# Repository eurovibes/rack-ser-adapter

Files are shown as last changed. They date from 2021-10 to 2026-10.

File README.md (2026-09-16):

<!-- SPDX-FileCopyrightText: 2021 Benedikt Spranger <b.spranger@linutronix.de> -->
<!-- SPDX-License-Identifier: CERN-OHL-S-2.0 -->






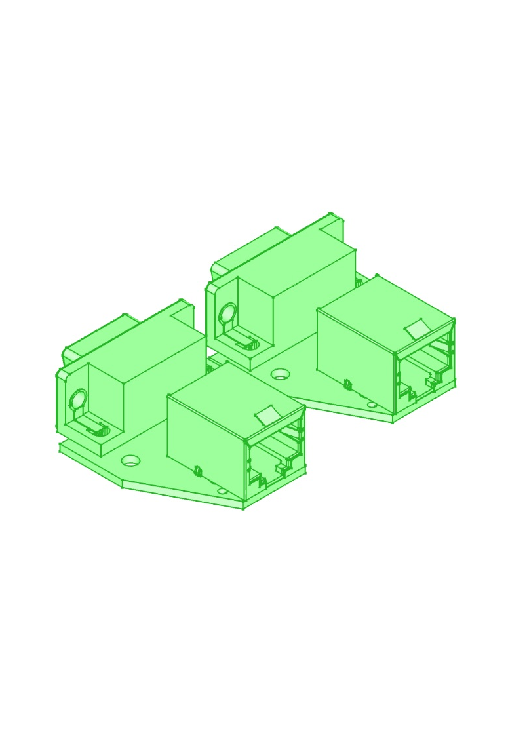
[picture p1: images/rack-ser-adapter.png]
rack-ser-adapter logo


# rack-ser-adapter -  RS232 DE-9 to EIA-561 RJ45 adapter

## Adapter pinout (EIA-561)

### 1:1

| DB-9 Pin | Signal	| RJ45 |
|---:|---|-----:|
1 | DCD | 2
2 | RxD | 5
3 | TxD | 6
4 | DTR | 3
5 | GND | 4
6 | DSR | 1
7 | RTS | 8
8 | CTS | 7
9 |  -  | -

### CROSSOVER / NULLMODEM

| RJ45 | Signal	| DB-9 Pin |
|-----:|---|---:|
1 | DTR | 4
2 | DCD | -
3 | DST | 6
4 | GND | 5
5 | TxD | 3
6 | RxD | 2
7 | RTS | 7
8 | CTS | 8
9 |  -  | -

## License rules

rack-ser-adapter is provided under the terms of the CERN-OHL-S license
version 2 as provided in the LICENSES/CERN-OHL-S-2.0 file.

Instead of adding license boilerplates to the individual files,
rack-ser-adapter uses SPDX license identifiers, which are machine parseable
and considered legaly equivalent.

The SPDX license identifier in rack-ser-adapter shall be added at the first
possible line in a file which can contain a comment. This is normally the
first line except for scripts. Scripts require the #!PATH_TO_INTERPRETER tag
in the first line; place the SPDX identifier into the second line.

The SPDX license identifier is added in form of a comment.

## Copyright and License

> Copyright Benedikt Spranger 2021.
> This source describes Open Hardware and is licensed under the CERNOHL-S v2.
> You may redistribute and modify this source and make products using it
> under the terms of the CERN-OHL-S v2 (https://ohwr.org/cern ohl s v2.txt ).
> This source is distributed WITHOUT ANY EXPRESS OR IMPLIED WARRANTY, INCLUDING
> OF MERCHANTABILITY, SATISFACTORY QUALITY AND FITNESS FOR A PARTICULAR PURPOSE.
> Please see the CERN-OHL-S v2 for applicable conditions.
> Source location: https://github.com/eurovibes/rack-ser-adapter
> As per CERN-OHL-S v2 section 4, should You produce hardware based
> on this source, You must where practicable maintain the Source Location
> visible on the external case of the rack-ser-adapter or other products you
> make using this source.

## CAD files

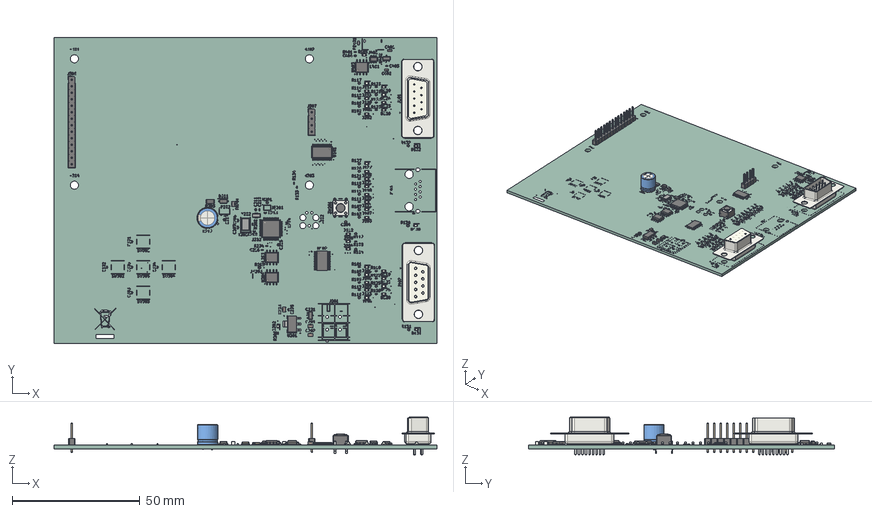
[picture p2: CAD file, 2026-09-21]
enclosure/tester.step
150.0 x 120.0 x 14.7 mm
C_0402_1005Metric x 19
R_0402_1005Metric x 40
LED_0603_1608Metric x 34
SOT-23-3
CP_Radial_D8.0mm_P3.50mm
PinHeader_1x04_P2.54mm_Vertical
PinHeader_1x14_P2.54mm_Vertical
C_0805_2012Metric x 3
SOT-23
Crystal_SMD_3215-2Pin_3.2x1.5mm
C_0603_1608Metric x 2
TSSOP-24_4.4x7.8mm_P0.65mm x 2
SW_PUSH_6mm
R_1206_3216Metric
JEITA_SOIC-8_3.9x4.9mm_P1.27mm
SOIC-8_3.9x4.9mm_P1.27mm x 2
SOT-23-6
DSUB-9_Socket_Vertical_P2.77x2.84mm_MountingHoles
SOT-223
L_0603_1608Metric
LQFP-48_7x7mm_P0.5mm
Crystal_SMD_5032-2Pin_5.0x3.2mm
DSUB-9_Pins_Vertical_P2.77x2.84mm_MountingHoles
D_SOD-123
L_0805_2012Metric
tester_silkscreen
tester_PCB

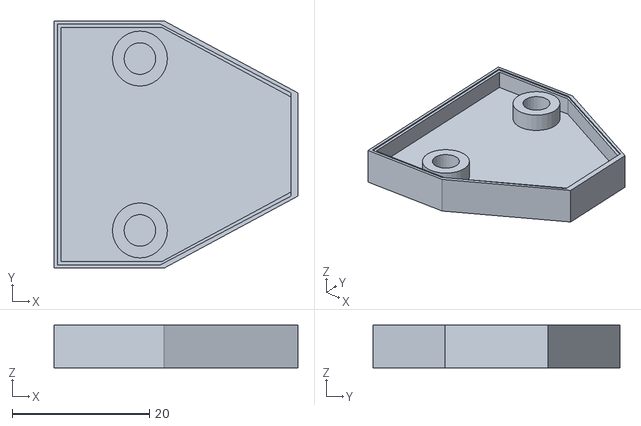
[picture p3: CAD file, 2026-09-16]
enclosure/rack-ser-adapter-rack-ser-adapter.stl
35.5 x 36.0 x 6.20

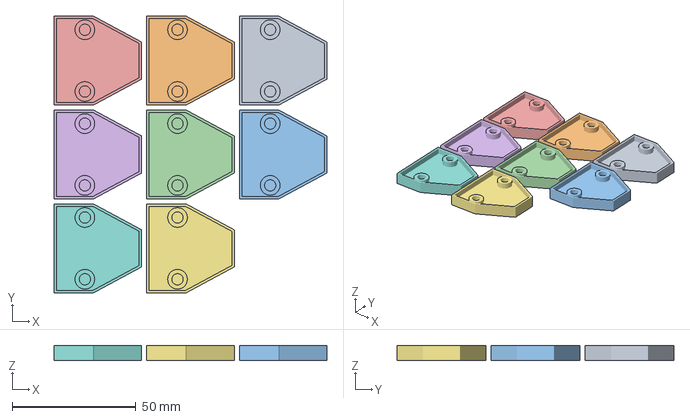
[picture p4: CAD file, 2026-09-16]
enclosure/AI3MSPRO_rack-ser-adapter-rack-ser-adapter.3mf
110.5 x 112.0 x 6.20 mm
rack-ser-adapter-rack-ser-adapter.stl x 8

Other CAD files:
enclosure/rack-ser-adapter.FCStd
enclosure/tester.FCStd

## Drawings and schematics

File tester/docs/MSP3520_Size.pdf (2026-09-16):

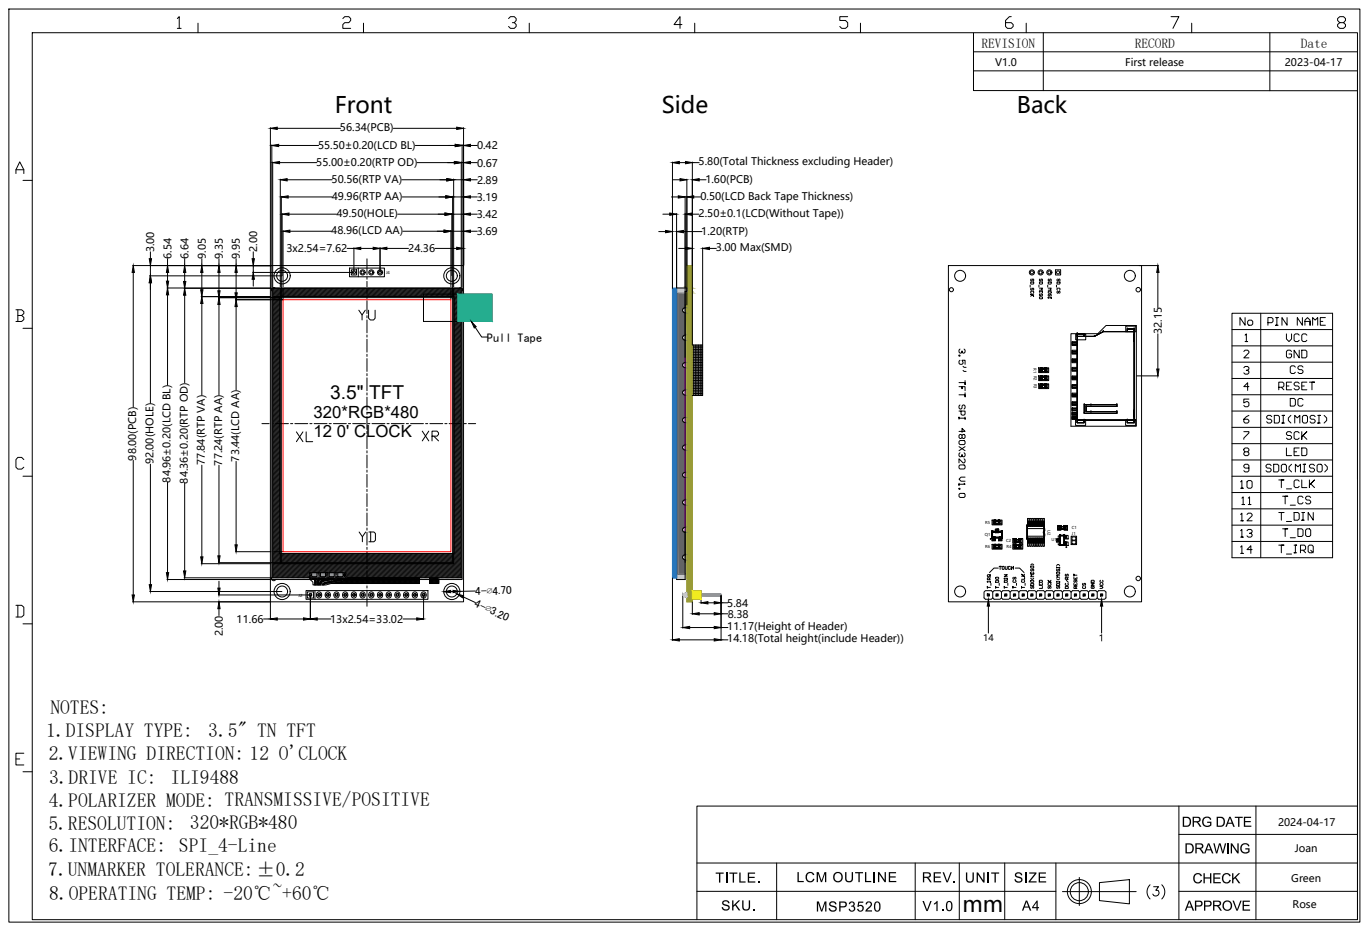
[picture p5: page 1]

3.003.69 3.42 1.60(PCB) 0.50(LCD Back Tape Thickness) 2.50±0.1(LCD(Without Tape)) 1.20(RTP) 5.80(Total Thickness excluding Header) 11.17(Height of Header) 5.84 8.38 14.18(Total height(include Header)) 3.00 Max(SMD) V1.0 First release 2023-04-17 3.5" TN TFT 12 O'CLOCK TRANSMISSIVE/POSITIVE 320*RGB*480 SPI_4-Line±0.2 -20℃~+60℃ ILI9488 V1.0 2024-04-17

73.44(LCD AA) 55.50±0.20(LCD BL) 55.00±0.20(RTP OD)

9.95 Pull Tape 3.5" TFT 320*RGB*480 12 0' CLOCK U1 R4

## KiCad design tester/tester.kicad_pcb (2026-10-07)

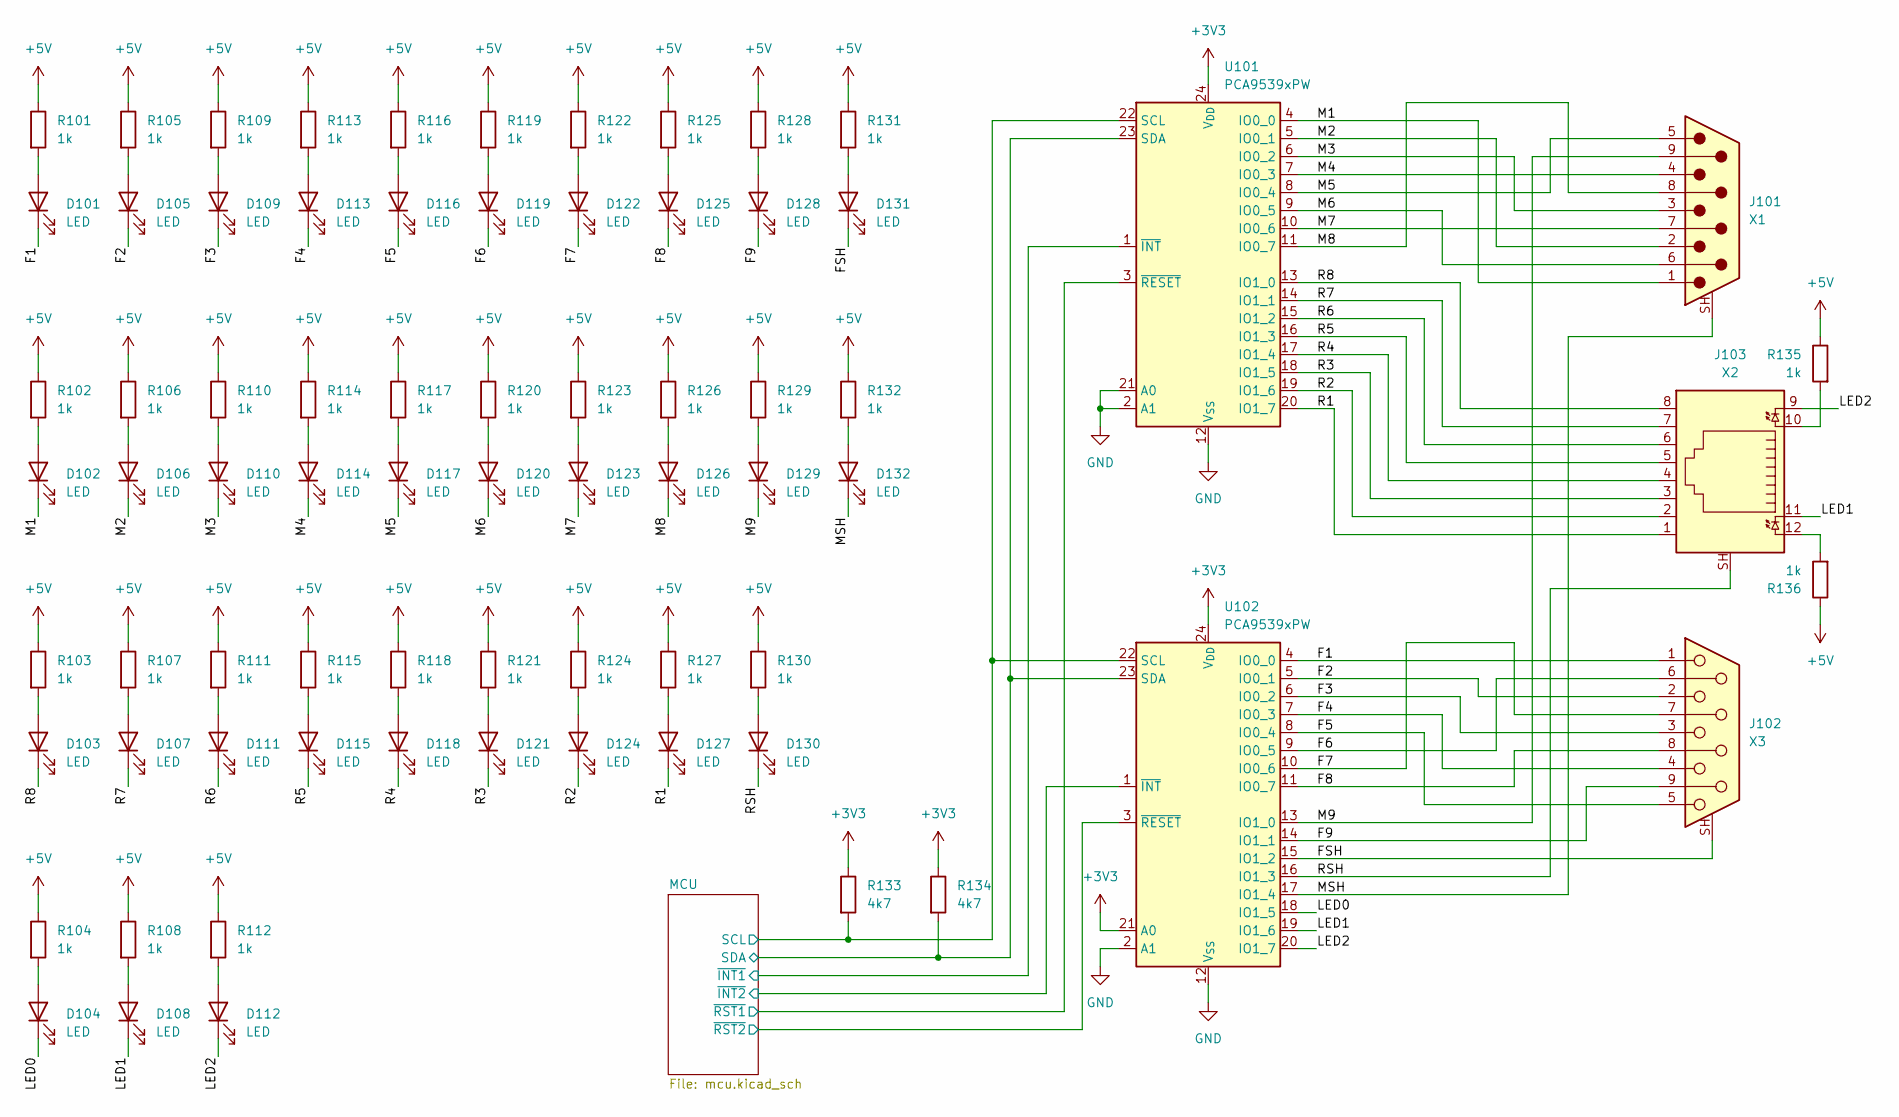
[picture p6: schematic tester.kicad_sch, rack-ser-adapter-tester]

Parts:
D101, D102, D103, D104, D105, D106, D107, D108, D109, D110, D111, D112, D113, D114, D115, D116, D117, D118, D119, D120, D121, D122, D123, D124, D125, D126, D127, D128, D129, D130, D131, D132: LED; LED_0603_1608Metric; mpn KT-0603W; LCSC# C2290
J101: X1; DSUB-9_Pins_Vertical_P2.77x2.84mm_MountingHoles; mpn DS1037-09MNAKT74-0CC
J102: X3; DSUB-9_Socket_Vertical_P2.77x2.84mm_MountingHoles; mpn DS1037-09FNAKT74-0CC
J103: X2; RJ45_Amphenol_RJHSE538X; mpn RJHSE5380
R101, R102, R103, R104, R105, R106, R107, R108, R109, R110, R111, R112, R113, R114, R115, R116, R117, R118, R119, R120, R121, R122, R123, R124, R125, R126, R127, R128, R129, R130, R131, R132, R135, R136: 1k; R_0402_1005Metric; mpn 0402WGF1001TCE; LCSC# C11702
R133, R134: 4k7; R_0402_1005Metric; mpn 0402WGF4701TCE; LCSC# C25900
U101, U102: PCA9539xPW; TSSOP-24_4.4x7.8mm_P0.65mm; mpn PCA9539PW; LCSC# C129516

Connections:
+3V3: R133.1, R134.1, U101.24 (V_{DD}), U102.21 (A0), U102.24 (V_{DD}); also elsewhere on the board
+5V: R101.1, R102.1, R103.1, R104.1, R105.1, R106.1, R107.1, R108.1, R109.1, R110.1, R111.1, R112.1, R113.1, R114.1, R115.1, R116.1, R117.1, R118.1, R119.1, R120.1, R121.1, R122.1, R123.1, R124.1, R125.1, R126.1, R127.1, R128.1, R129.1, R130.1, R131.1, R132.1, R135.1, R136.1; also elsewhere on the board
/F1: D101.1 (K), J102.1, U102.4 (IO0_0)
/F2: D105.1 (K), J102.2, U102.5 (IO0_1)
/F3: D109.1 (K), J102.3, U102.6 (IO0_2)
/F4: D113.1 (K), J102.4, U102.7 (IO0_3)
/F5: D116.1 (K), J102.5, U102.8 (IO0_4)
/F6: D119.1 (K), J102.6, U102.9 (IO0_5)
/F7: D122.1 (K), J102.7, U102.10 (IO0_6)
/F8: D125.1 (K), J102.8, U102.11 (IO0_7)
/F9: D128.1 (K), J102.9, U102.14 (IO1_1)
/FSH: D131.1 (K), J102.SH (PAD), U102.15 (IO1_2)
/LED0: D104.1 (K), U102.18 (IO1_5)
/LED1: D108.1 (K), J103.11, U102.19 (IO1_6)
/LED2: D112.1 (K), J103.9, U102.20 (IO1_7)
/M1: D102.1 (K), J101.1, U101.4 (IO0_0)
/M2: D106.1 (K), J101.2, U101.5 (IO0_1)
/M3: D110.1 (K), J101.3, U101.6 (IO0_2)
/M4: D114.1 (K), J101.4, U101.7 (IO0_3)
/M5: D117.1 (K), J101.5, U101.8 (IO0_4)
/M6: D120.1 (K), J101.6, U101.9 (IO0_5)
/M7: D123.1 (K), J101.7, U101.10 (IO0_6)
/M8: D126.1 (K), J101.8, U101.11 (IO0_7)
/M9: D129.1 (K), J101.9, U102.13 (IO1_0)
/MCU/SCL: R133.2, U101.22 (SCL), U102.22 (SCL); also elsewhere on the board
/MCU/SDA: R134.2, U101.23 (SDA), U102.23 (SDA); also elsewhere on the board
/MCU/~INT1: U101.1 (~INT); also elsewhere on the board
/MCU/~INT2: U102.1 (~INT); also elsewhere on the board
/MCU/~RST1: U101.3 (~RESET); also elsewhere on the board
/MCU/~RST2: U102.3 (~RESET); also elsewhere on the board
/MSH: D132.1 (K), J101.SH (PAD), U102.17 (IO1_4)
/R1: D127.1 (K), J103.1, U101.20 (IO1_7)
/R2: D124.1 (K), J103.2, U101.19 (IO1_6)
/R3: D121.1 (K), J103.3, U101.18 (IO1_5)
/R4: D118.1 (K), J103.4, U101.17 (IO1_4)
/R5: D115.1 (K), J103.5, U101.16 (IO1_3)
/R6: D111.1 (K), J103.6, U101.15 (IO1_2)
/R7: D107.1 (K), J103.7, U101.14 (IO1_1)
/R8: D103.1 (K), J103.8, U101.13 (IO1_0)
/RSH: D130.1 (K), J103.SH, U102.16 (IO1_3)
GND: U101.2 (A1), U101.12 (V_{SS}), U101.21 (A0), U102.2 (A1), U102.12 (V_{SS}); also elsewhere on the board
unnamed: D101.2 (A), R101.2
unnamed: D102.2 (A), R102.2
unnamed: D103.2 (A), R103.2
unnamed: D104.2 (A), R104.2
unnamed: D105.2 (A), R105.2
unnamed: D106.2 (A), R106.2
unnamed: D107.2 (A), R107.2
unnamed: D108.2 (A), R108.2
unnamed: D109.2 (A), R109.2
unnamed: D110.2 (A), R110.2
unnamed: D111.2 (A), R111.2
unnamed: D112.2 (A), R112.2
unnamed: D113.2 (A), R113.2
unnamed: D114.2 (A), R114.2
unnamed: D115.2 (A), R115.2
unnamed: D116.2 (A), R116.2
unnamed: D117.2 (A), R117.2
unnamed: D118.2 (A), R118.2
unnamed: D119.2 (A), R119.2
unnamed: D120.2 (A), R120.2
unnamed: D121.2 (A), R121.2
unnamed: D122.2 (A), R122.2
unnamed: D123.2 (A), R123.2
unnamed: D124.2 (A), R124.2
unnamed: D125.2 (A), R125.2
unnamed: D126.2 (A), R126.2
unnamed: D127.2 (A), R127.2
unnamed: D128.2 (A), R128.2
unnamed: D129.2 (A), R129.2
unnamed: D130.2 (A), R130.2
unnamed: D131.2 (A), R131.2
unnamed: D132.2 (A), R132.2
unnamed: J103.10, R135.2
unnamed: J103.12, R136.2

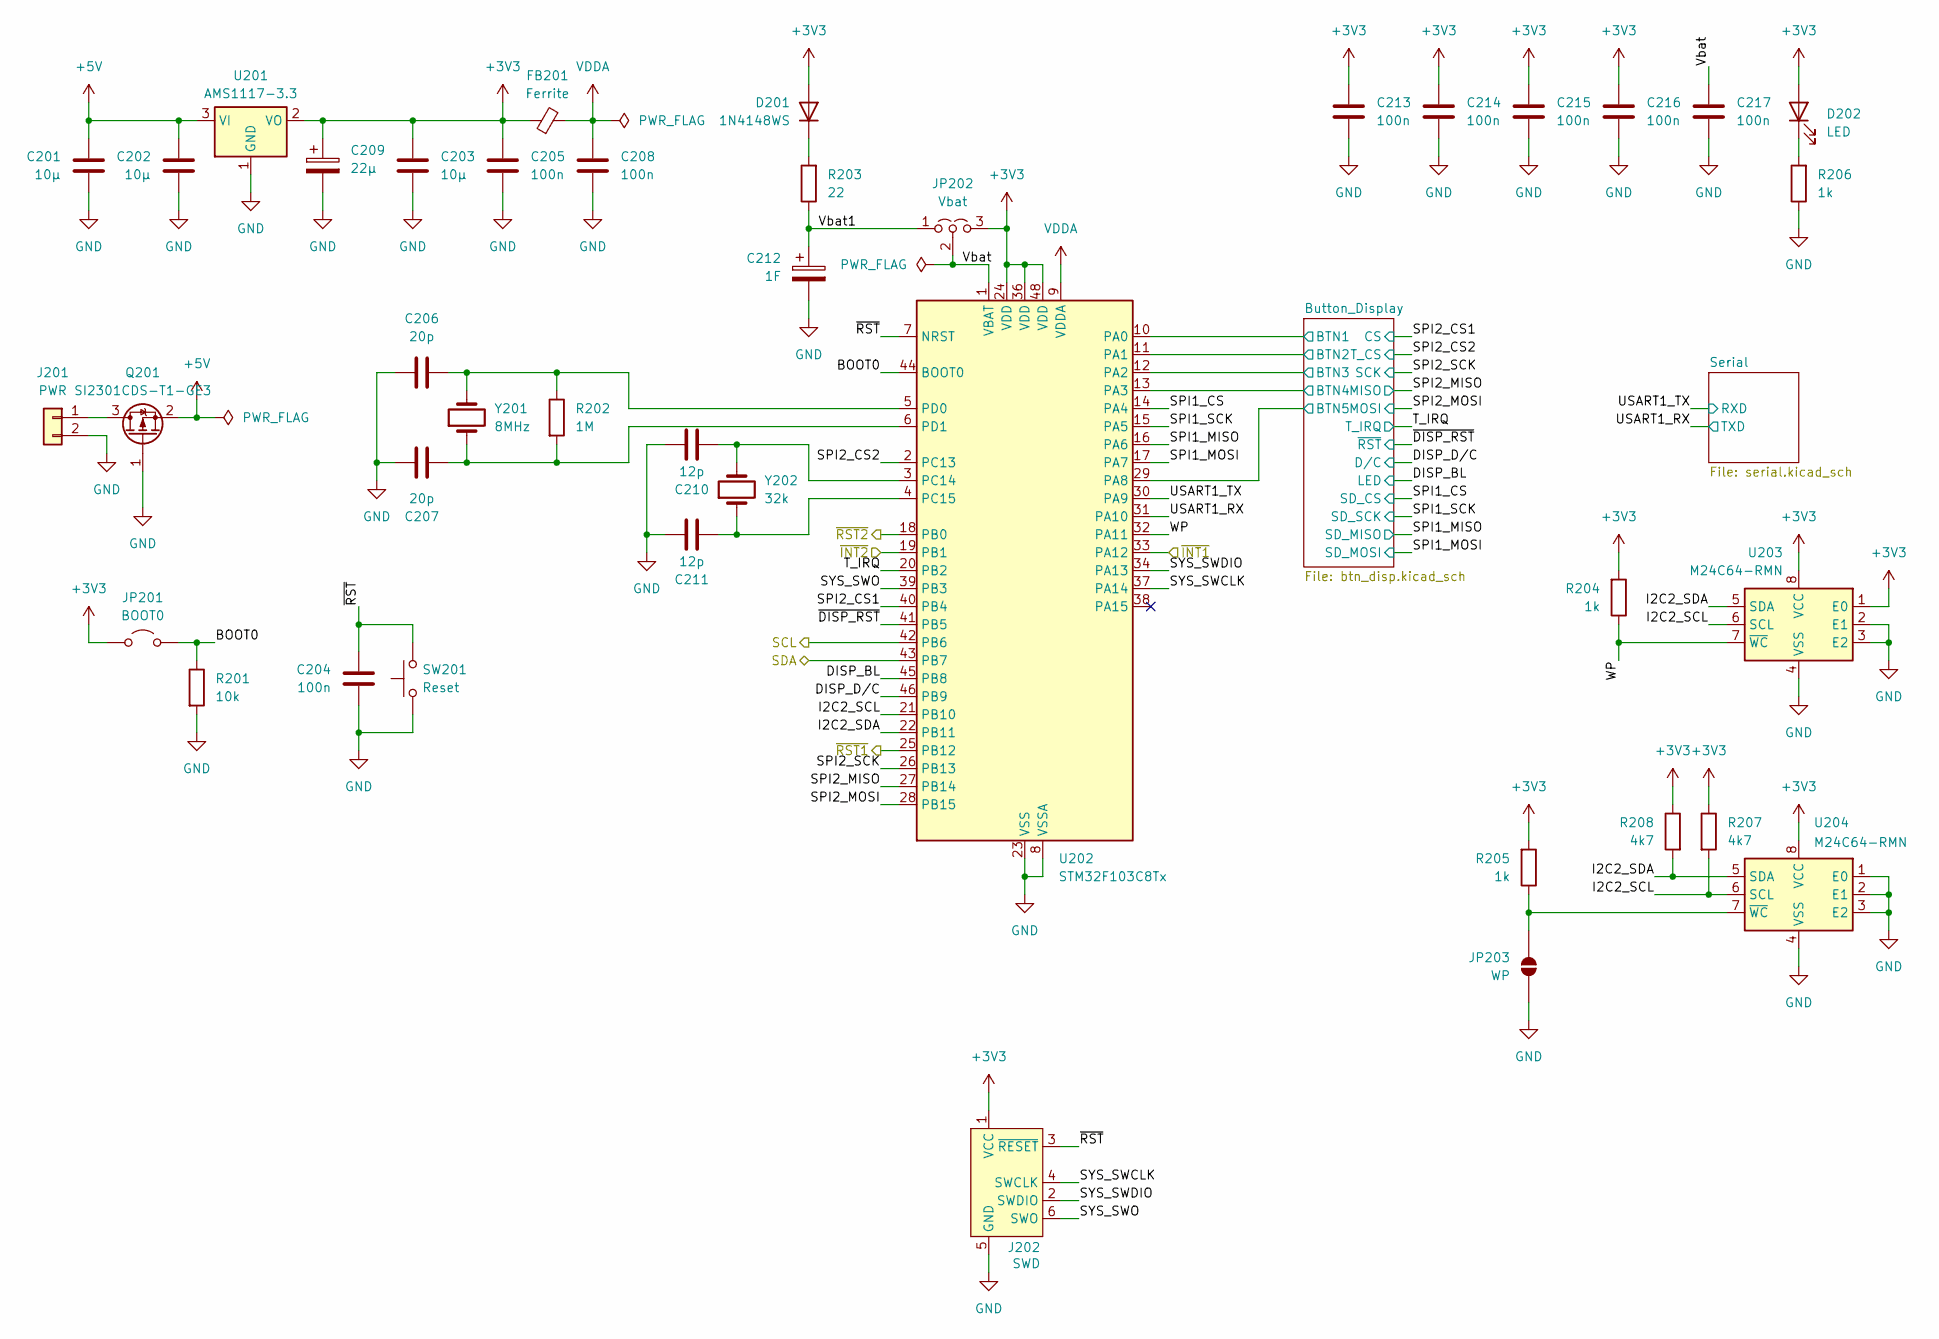
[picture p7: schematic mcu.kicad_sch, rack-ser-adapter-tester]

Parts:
C201, C202, C203: 10µ; C_0805_2012Metric; mpn CL21A106KAYNNNE; LCSC# C15850
C204, C205, C208, C213, C214, C215, C216, C217: 100n; C_0402_1005Metric; mpn CL05B104KB54PNC; LCSC# C307331
C206, C207: 20p; C_0402_1005Metric; mpn 0402CG200J500NT; LCSC# C1554
C209: 22µ; CP_EIA-3216-18_Kemet-A; mpn CA45-A-10V-22uF-K; LCSC# C129272
C210, C211: 12p; C_0402_1005Metric; mpn 0402CG120J500NT; LCSC# C1547
C212: 1F; CP_Radial_D8.0mm_P3.50mm
D201: 1N4148WS; D_SOD-123; mpn 1N4148W; LCSC# C81598
D202: LED; LED_0603_1608Metric; mpn KT-0603R; LCSC# C2286
FB201: Ferrite; L_0805_2012Metric; mpn GZ2012D101TF; LCSC# C1015
J201: PWR; TerminalBlock_WAGO_236-402_1x02_P5.00mm_45Degree
J202: SWD; Tag-Connect_TC2030-IDC-FP_2x03_P1.27mm_Vertical
JP201: BOOT0; SolderJumper-2_P1.3mm_Open_Pad1.0x1.5mm
JP202: Vbat; SolderJumper-3_P1.3mm_Open_Pad1.0x1.5mm
JP203: WP; SolderJumper-2_P1.3mm_Open_Pad1.0x1.5mm
Q201: SI2301CDS-T1-GE3; SOT-23; mpn SI2301CDS-T1-GE3; LCSC# C10487
R201: 10k; R_0402_1005Metric; mpn 0402WGF1002TCE; LCSC# C25744
R202: 1M; R_0402_1005Metric; mpn 0402WGF1004TCE; LCSC# C26083
R203: 22; R_1206_3216Metric; mpn 1206W4F220JT5E; LCSC# C17958
R204, R205, R206: 1k; R_0402_1005Metric; mpn 0402WGF1001TCE; LCSC# C11702
R207, R208: 4k7; R_0402_1005Metric; mpn 0402WGF4701TCE; LCSC# C25900
SW201: Reset; SW_PUSH_6mm; mpn TACT-65R-F
U201: AMS1117-3.3; SOT-223-3_TabPin2; mpn AMS1117-3.3; LCSC# C6186
U202: STM32F103C8Tx; LQFP-48_7x7mm_P0.5mm; mpn STM32F103C8T6; LCSC# C8734
U203, U204: M24C64-RMN; SOIC-8_3.9x4.9mm_P1.27mm; mpn M24C64-RMN6TP; LCSC# C79988
Y201: 8MHz; Crystal_SMD_5032-2Pin_5.0x3.2mm; mpn X50328MSB2GI; LCSC# C115962
Y202: 32k; Crystal_SMD_3215-2Pin_3.2x1.5mm; mpn Q13FC13500004; LCSC# C32346

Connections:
+3V3: C203.1, C205.1, C209.1, C213.1, C214.1, C215.1, C216.1, D201.2 (A), D202.2 (A), FB201.1, J202.1 (VCC), JP201.1 (A), JP202.3 (B), R204.2, R205.2, R207.1, R208.1, U201.2 (VO), U202.24 (VDD), U202.36 (VDD), U202.48 (VDD), U203.1 (E0), U203.8 (VCC), U204.8 (VCC); also elsewhere on the board
+5V: C201.1, C202.1, Q201.2 (S), U201.3 (VI); also elsewhere on the board
/MCU/BOOT0: JP201.2 (B), R201.1, U202.44 (BOOT0)
/MCU/Button_Display/BTN1: U202.10 (PA0); also elsewhere on the board
/MCU/Button_Display/BTN2: U202.11 (PA1); also elsewhere on the board
/MCU/Button_Display/BTN3: U202.12 (PA2); also elsewhere on the board
/MCU/Button_Display/BTN4: U202.13 (PA3); also elsewhere on the board
/MCU/Button_Display/BTN5: U202.29 (PA8); also elsewhere on the board
/MCU/DISP_BL: U202.45 (PB8); also elsewhere on the board
/MCU/DISP_D/C: U202.46 (PB9); also elsewhere on the board
/MCU/I2C2_SCL: R207.2, U202.21 (PB10), U203.6 (SCL), U204.6 (SCL)
/MCU/I2C2_SDA: R208.2, U202.22 (PB11), U203.5 (SDA), U204.5 (SDA)
/MCU/SCL: U202.42 (PB6); also elsewhere on the board
/MCU/SDA: U202.43 (PB7); also elsewhere on the board
/MCU/SPI1_CS: U202.14 (PA4); also elsewhere on the board
/MCU/SPI1_MISO: U202.16 (PA6); also elsewhere on the board
/MCU/SPI1_MOSI: U202.17 (PA7); also elsewhere on the board
/MCU/SPI1_SCK: U202.15 (PA5); also elsewhere on the board
/MCU/SPI2_CS1: U202.40 (PB4); also elsewhere on the board
/MCU/SPI2_CS2: U202.2 (PC13); also elsewhere on the board
/MCU/SPI2_MISO: U202.27 (PB14); also elsewhere on the board
/MCU/SPI2_MOSI: U202.28 (PB15); also elsewhere on the board
/MCU/SPI2_SCK: U202.26 (PB13); also elsewhere on the board
/MCU/SYS_SWCLK: J202.4 (SWCLK), U202.37 (PA14)
/MCU/SYS_SWDIO: J202.2 (SWDIO), U202.34 (PA13)
/MCU/SYS_SWO: J202.6 (SWO), U202.39 (PB3)
/MCU/T_IRQ: U202.20 (PB2); also elsewhere on the board
/MCU/USART1_RX: U202.31 (PA10); also elsewhere on the board
/MCU/USART1_TX: U202.30 (PA9); also elsewhere on the board
/MCU/Vbat: C217.1, JP202.2 (C), U202.1 (VBAT)
/MCU/Vbat1: C212.1, JP202.1 (A), R203.1
/MCU/WP: R204.1, U202.32 (PA11), U203.7 (~WC)
/MCU/~DISP_RST: U202.41 (PB5); also elsewhere on the board
/MCU/~INT1: U202.33 (PA12); also elsewhere on the board
/MCU/~INT2: U202.19 (PB1); also elsewhere on the board
/MCU/~RST1: U202.25 (PB12); also elsewhere on the board
/MCU/~RST2: U202.18 (PB0); also elsewhere on the board
/MCU/~RST: C204.1, J202.3 (~RESET), SW201.2, U202.7 (NRST)
GND: C201.2, C202.2, C203.2, C204.2, C205.2, C206.1, C207.1, C208.2, C209.2, C210.1, C211.1, C212.2, C213.2, C214.2, C215.2, C216.2, C217.2, J201.2, J202.5 (GND), JP203.1 (A), Q201.1 (G), R201.2, R206.1, SW201.1, U201.1 (GND), U202.8 (VSSA), U202.23 (VSS), U202.35 (VSS), U202.47 (VSS), U203.2 (E1), U203.3 (E2), U203.4 (VSS), U204.1 (E0), U204.2 (E1), U204.3 (E2), U204.4 (VSS); also elsewhere on the board
unnamed: D201.1 (K), R203.2
unnamed: D202.1 (K), R206.2
unnamed: J201.1, Q201.3 (D)
unnamed: JP203.2 (B), R205.1, U204.7 (~WC)
unnamed: C210.2, U202.3 (PC14), Y202.2
unnamed: C211.2, U202.4 (PC15), Y202.1
unnamed: C206.2, R202.1, U202.5 (PD0), Y201.2
unnamed: C207.2, R202.2, U202.6 (PD1), Y201.1
VDDA: C208.1, FB201.2, U202.9 (VDDA)

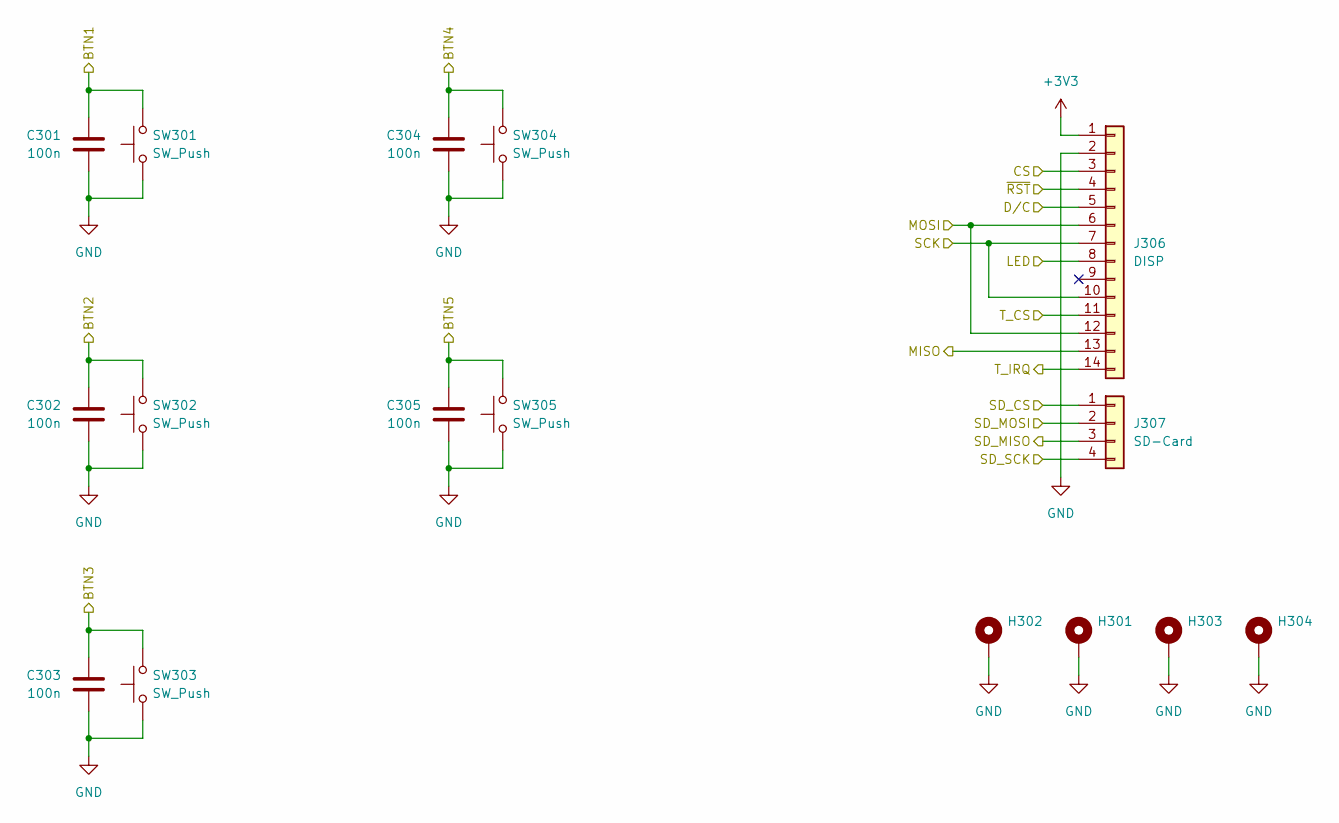
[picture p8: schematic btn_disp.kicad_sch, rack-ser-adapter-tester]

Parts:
C301, C302, C303, C304, C305: 100n; C_0402_1005Metric; mpn CL05B104KB54PNC; LCSC# C307331
H301, H302, H303, H304: MountingHole_3.2mm_M3_ISO14580_Pad
J306: DISP; PinHeader_1x14_P2.54mm_Vertical
J307: SD-Card; PinHeader_1x04_P2.54mm_Vertical
SW301, SW302, SW303, SW304, SW305: SW_Push; TS-1187A-B-A-B; mpn TS-1187A-B-A-B; LCSC# C318884

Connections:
+3V3: J306.1; also elsewhere on the board
/MCU/Button_Display/BTN1: C301.1, SW301.2; also elsewhere on the board
/MCU/Button_Display/BTN2: C302.1, SW302.2; also elsewhere on the board
/MCU/Button_Display/BTN3: C303.1, SW303.2; also elsewhere on the board
/MCU/Button_Display/BTN4: C304.1, SW304.2; also elsewhere on the board
/MCU/Button_Display/BTN5: C305.1, SW305.2; also elsewhere on the board
/MCU/DISP_BL: J306.8; also elsewhere on the board
/MCU/DISP_D/C: J306.5; also elsewhere on the board
/MCU/SPI1_CS: J307.1; also elsewhere on the board
/MCU/SPI1_MISO: J307.3; also elsewhere on the board
/MCU/SPI1_MOSI: J307.2; also elsewhere on the board
/MCU/SPI1_SCK: J307.4; also elsewhere on the board
/MCU/SPI2_CS1: J306.3; also elsewhere on the board
/MCU/SPI2_CS2: J306.11; also elsewhere on the board
/MCU/SPI2_MISO: J306.13; also elsewhere on the board
/MCU/SPI2_MOSI: J306.6, J306.12; also elsewhere on the board
/MCU/SPI2_SCK: J306.7, J306.10; also elsewhere on the board
/MCU/T_IRQ: J306.14; also elsewhere on the board
/MCU/~DISP_RST: J306.4; also elsewhere on the board
GND: C301.2, C302.2, C303.2, C304.2, C305.2, H301.1 (1_1), H302.1 (1_1), H303.1 (1_1), H304.1 (1_1), J306.2, SW301.1, SW302.1, SW303.1, SW304.1, SW305.1; also elsewhere on the board

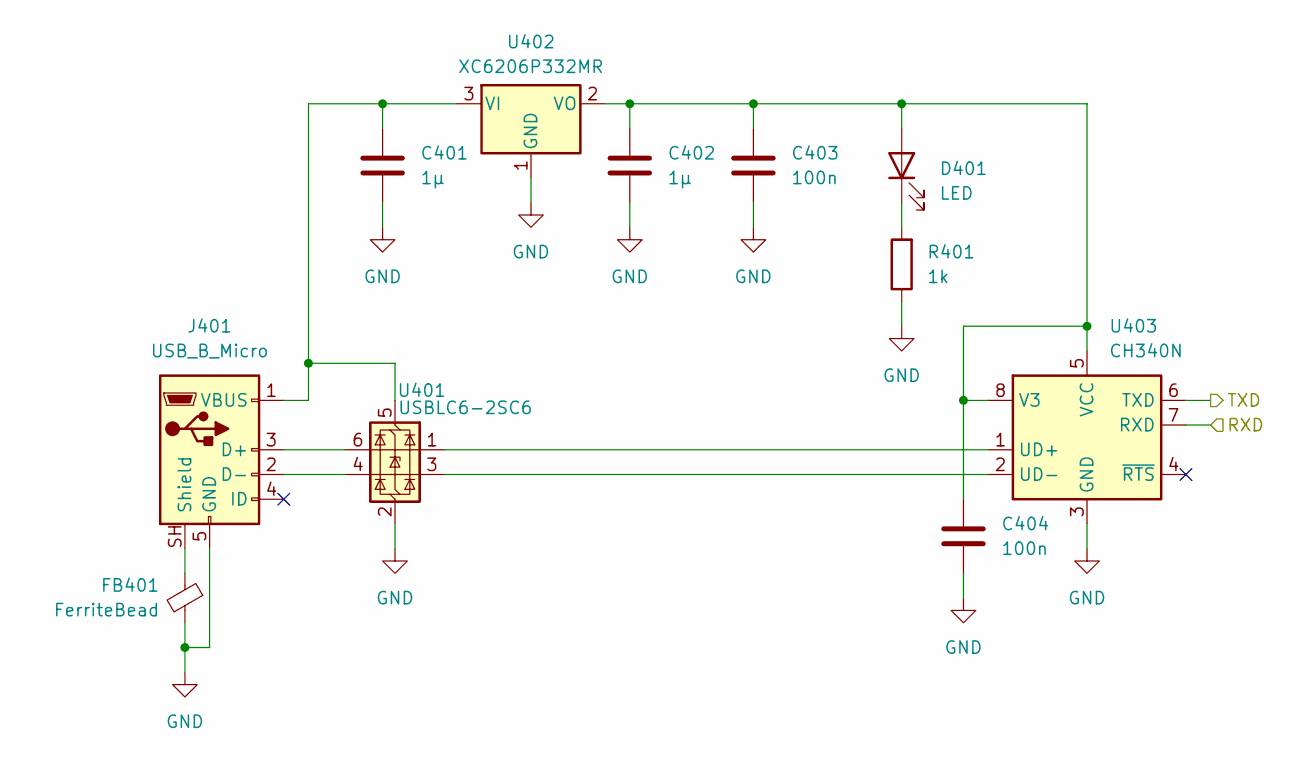
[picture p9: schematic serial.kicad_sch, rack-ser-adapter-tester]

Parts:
C401, C402: 1µ; C_0603_1608Metric; mpn CL10A105KB8NNNC; LCSC# C15849
C403, C404: 100n; C_0402_1005Metric; mpn CL05B104KB54PNC; LCSC# C307331
D401: LED; LED_0603_1608Metric; mpn KT-0603R; LCSC# C2286
FB401: FerriteBead; L_0603_1608Metric; mpn GZ1608D601TF; LCSC# C1002
J401: USB_B_Micro; USB_Micro-B_Amphenol_10118193-0001LF_Horizontal; mpn 10118193-0001LF; LCSC# C132562
R401: 1k; R_0402_1005Metric; mpn 0402WGF1001TCE; LCSC# C11702
U401: USBLC6-2SC6; SOT-23-6; mpn USBLC6-2SC6; LCSC# C2827654
U402: XC6206P332MR; SOT-23-3; mpn XC6206P332MR-G; LCSC# C5446
U403: CH340N; JEITA_SOIC-8_3.9x4.9mm_P1.27mm; mpn CH340N; LCSC# C2977777

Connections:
/MCU/USART1_RX: U403.6 (TXD); also elsewhere on the board
/MCU/USART1_TX: U403.7 (RXD); also elsewhere on the board
GND: C401.2, C402.2, C403.2, C404.2, FB401.2, J401.5 (GND), R401.1, U401.2 (GND), U402.1 (GND), U403.3 (GND); also elsewhere on the board
unnamed: C402.1, C403.1, C404.1, D401.2 (A), U402.2 (VO), U403.5 (VCC), U403.8 (V3)
unnamed: D401.1 (K), R401.2
unnamed: J401.3 (D+), U401.6 (I/O1)
unnamed: J401.2 (D-), U401.4 (I/O2)
unnamed: FB401.1, J401.SH (Shield)
unnamed: C401.1, J401.1 (VBUS), U401.5 (VBUS), U402.3 (VI)
unnamed: U401.1 (I/O1), U403.1 (UD+)
unnamed: U401.3 (I/O2), U403.2 (UD-)

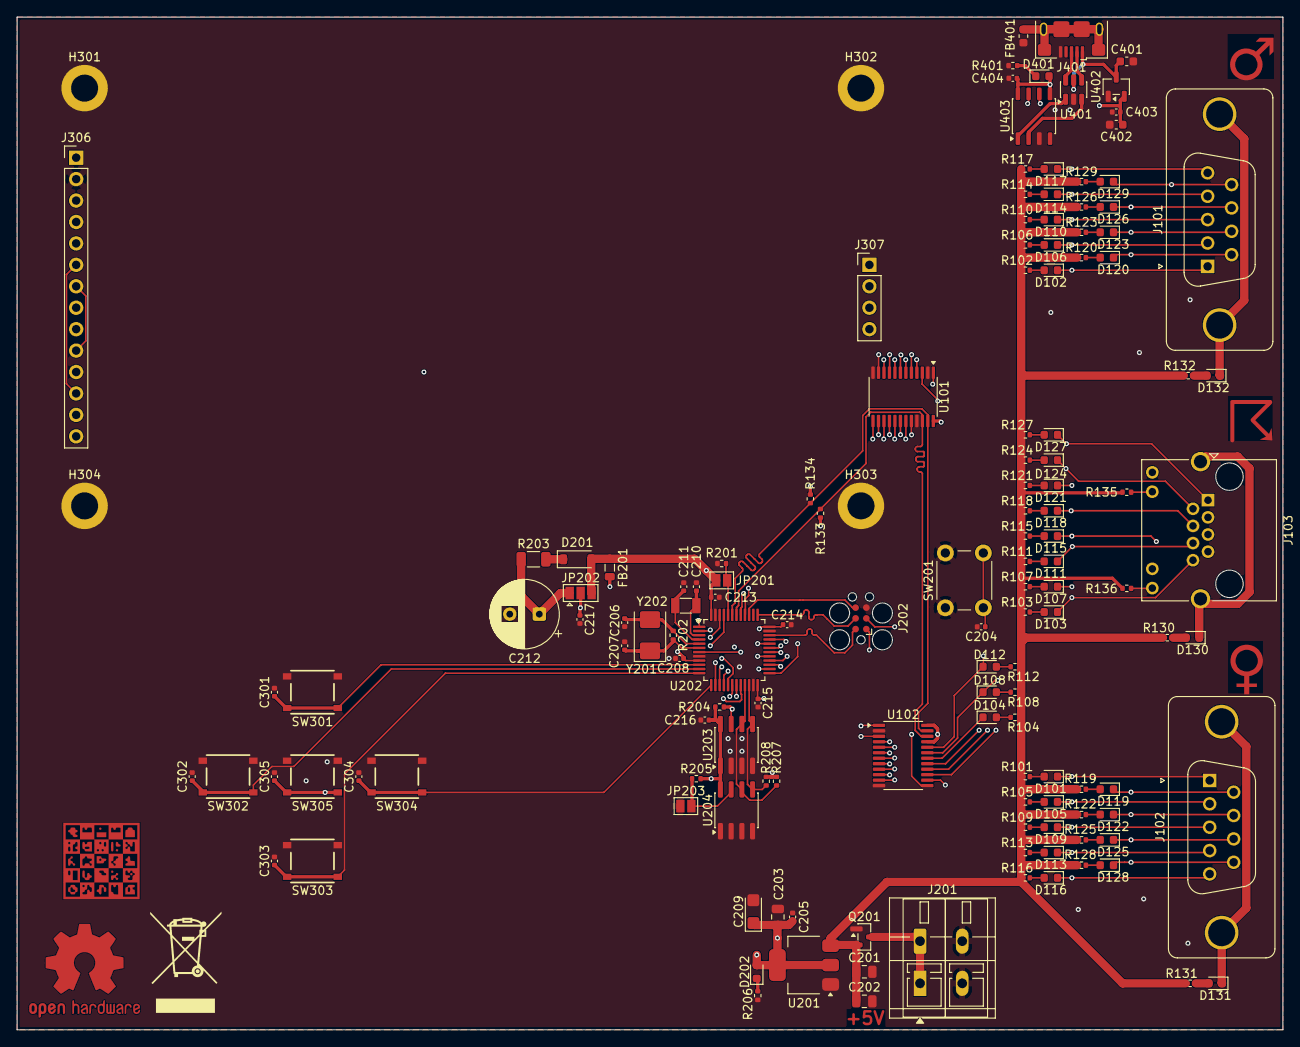
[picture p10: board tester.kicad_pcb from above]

Board: 4 copper layers, 150.0 x 120.0 mm, 141 parts (0 on the bottom side), 122 nets.

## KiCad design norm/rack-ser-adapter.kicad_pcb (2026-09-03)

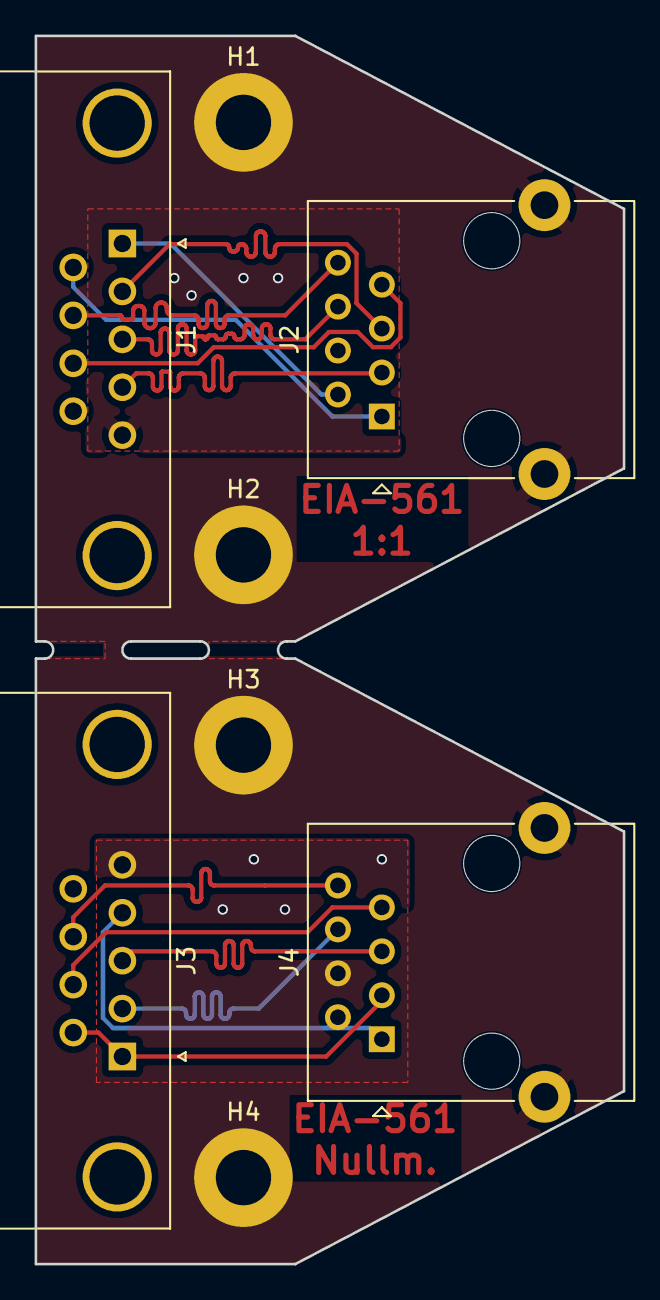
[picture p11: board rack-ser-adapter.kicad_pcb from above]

Board: 2 copper layers, 34.0 x 71.0 mm, 8 parts (0 on the bottom side), 15 nets.

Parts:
H1, H2, H3, H4: MountingHole_3.2mm_M3_ISO7380_Pad
J1: RS-232; DSUB-9_Male_Horizontal_P2.77x2.84mm_EdgePinOffset4.94mm_Hou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
J2, J4: RJ45_Shielded; RJ45_Ninigi_GE
J3: RS-232; DSUB-9_Female_Horizontal_P2.77x2.84mm_EdgePinOffset4.94mm_H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

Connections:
/CTS: J1.8, J2.7
/CTS_1: J3.7, J4.7
/DCD: J1.1, J2.2
/DCD_1: J3.4, J4.1, J4.2
/DSR: J1.6, J2.1
/DTR: J1.4, J2.3
/DTR_1: J3.1, J3.6, J4.3
/RTS: J1.7, J2.8
/RTS_1: J3.8, J4.8
/RX: J1.2, J2.5
/RX_1: J3.3, J4.5
/SH: H1.1 (1_1), H2.1 (1_1), H3.1 (1_1), H4.1 (1_1), J2.SH, J4.SH
/TX: J1.3, J2.6
/TX_1: J3.2, J4.6
GND: J1.5, J2.4, J3.5, J4.4

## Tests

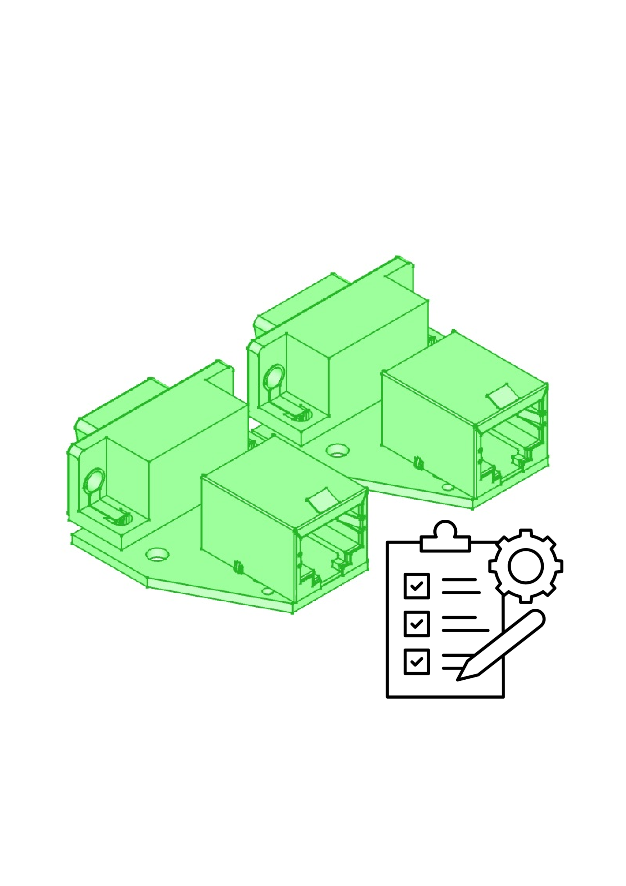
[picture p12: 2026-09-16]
images/rack-ser-adapter-tester.png

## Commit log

2021-11-01 Change breakaway tabs width
    [rack-ser-adapter.kicad_pcb]
2021-11-01 Edit BOM
    [rack-ser-adapter.sch]
2021-11-16 Add enclosure
    [MTJ-88GX1-FSD.step, rack-ser-adapter.FCStd, rack-ser-adapter.kicad_pcb]
2026-08-20 Update to KiCAD 10
    [rack-ser-adapter.kicad_pcb, rack-ser-adapter.kicad_sch, rack-ser-adapter.sch]
2026-09-01 Prepare to split project to norm and invers
    [rack-ser-adapter.kicad_pcb, rack-ser-adapter.kicad_sch]
2026-09-01 Change pin in footprint to match symbol
    [rack-ser-adapter.kicad_pcb]
2026-09-03 Add inverse adapter
    [rack-ser-adapter-inv.kicad_pcb, rack-ser-adapter-inv.kicad_sch]
2026-09-03 Change PCB color for inverse Board
2026-09-03 Prepare version 0.2
    [rack-ser-adapter-inv.kicad_pcb, rack-ser-adapter-inv.kicad_sch, rack-ser-adapter.kicad_pcb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]
2026-09-16 Add enclosure for adapter
    [AI3MSPRO_rack-ser-adapter-rack-ser-adapter.3mf, rack-ser-adapter-rack-ser-adapter.stl, rack-ser-adapter.FCStd]
2026-09-16 Add adapter tester
    [btn_disp.kicad_sch, mcu.kicad_sch, serial.kicad_sch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]
2026-09-16 Add automation for tester
    [btn_disp.kicad_sch, mcu.kicad_sch, serial.kicad_sch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]
2026-09-16 Add additional GND vias
    [tester.kicad_pcb]
2026-09-16 Mark Pushswitches as SMD parts
    [tester.kicad_pcb]
2026-09-16 Set PCB origin
    [tester.kicad_pcb]
2026-09-21 Add enclosure for adapter tester
    [tester.FCStd, tester.step]
2026-09-21 Use correct part for D201
    [mcu.kicad_sch, tester.kicad_pcb]
2026-09-23 Fix USB connector part information
    [serial.kicad_sch, tester.kicad_pcb]
2026-09-30 Rework RJ45 connector
    [tester.kicad_pcb, tester.kicad_sch]
2026-10-04 Fix SWD
    [mcu.kicad_sch, tester.kicad_pcb]
2026-10-04 Add missing I2C pullups
    [mcu.kicad_sch, tester.kicad_pcb]
2026-10-04 Enable CH340N 3.3V operation
    [serial.kicad_sch, tester.kicad_pcb]
2026-10-04 Use RJ45 connector with LEDs
    [tester.kicad_pcb, tester.kicad_sch]
2026-10-06 Add markings
    [tester.kicad_pcb]
2026-10-07 Add LDO recommended tantalum capacitor
    [btn_disp.kicad_sch, mcu.kicad_sch, serial.kicad_sch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]
2026-10-14 Add connector marker

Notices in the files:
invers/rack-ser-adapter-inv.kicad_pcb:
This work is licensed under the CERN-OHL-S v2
